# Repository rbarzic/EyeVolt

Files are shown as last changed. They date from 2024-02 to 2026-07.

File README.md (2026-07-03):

# Presentation

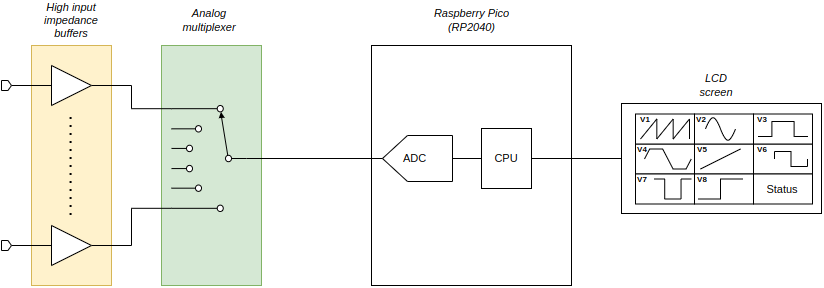
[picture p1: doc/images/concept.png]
General concept


EyeVolt 2.0 is a **12-channel DC voltage monitor** **and** an **8-channel
programmable DC voltage generator**, both built around a single Raspberry Pi
Pico (the RP2040 `U9`).

On the **monitor** side the Pico continuously samples up to twelve external
voltages and streams the raw ADC readings out over USB-serial, exactly like
v1.1. On the **generation** side the Pico produces eight independent 0 - 3.3 V
outputs by low-pass-filtering eight PWM channels and buffering them; a feedback
multiplexer lets the Pico read its own generated outputs back.

A Python **Terminal User Interface (TUI)** on the PC displays the live
monitored values, progress bars and sparkline trends. The PC software can
optionally expose the readings through an **MCP (Model Context Protocol)
server** so that AI assistants / automation can query the voltages
programmatically.

> **Software status (2.0):** the firmware and PC software currently committed
> in this repository are the **v1.1 code** — they implement the original
> voltage-monitoring protocol only and do **not** yet match the 2.0 hardware.
> See the [Software status](#software-status-20) section below for what works
> today and what is still to be done.

The board has two monitoring domains (unchanged ranges from v1.1):

| Group | Channels | Full-scale | Conditioning | Routed to |
|---|---|---|---|---|
| Low-voltage  | 0 - 7  (8 ch) | 0 - 3.3 V | unity-gain buffer only | MUX0 -> MUX1 (CH4) -> ADC0 (GP26) |
| High-voltage | 8 - 11 (4 ch) | 0 - 6.6 V | buffer + 2:1 resistive divider (÷2)  | MUX1 (CH0-CH3) -> ADC0 (GP26) |

Because the RP2040 ADC only accepts 0 - 3.3 V, the high-voltage channels are
divided by two on the board (so 6.6 V at the input => 3.3 V at the ADC); the PC
software then multiplies back by two to display the true input voltage.

---

# Hardware

## What changed from v1.1

The 2.0 board keeps the exact same 12-channel voltage-monitoring function and
ranges as v1.1, but the analog multiplexing hardware was reworked, and a full
voltage-generation stage was added:

| Area | v1.1 | v2.0 |
|---|---|---|
| Monitor MUX topology | two independent 74HCT4051, each feeding its own ADC pin (MUX0->GP26, MUX1->GP27) | the two 74HCT4051 are **cascaded** and only **one** ADC pin is used for monitoring (MUX0 -> MUX1 CH4 -> GP26) |
| Monitor select lines | MUX0: S0/S1/S2 = GP10/11/12, MUX1: S0/S1/S2 = GP21/20/19 | MUX0: S0/S1/S2 = **GP12/11/10**, MUX1: S0/S1/S2 = **GP19/20/21** (S0 and S2 swapped on both muxes; `~E` and S1 unchanged) |
| High-voltage input nets | `V55IN0..3` | `V50IN0..3` (same ÷2 divider, same 0 - 6.6 V range — name only) |
| Voltage generation | none | **8 PWM outputs (GP2-GP9)** -> 2nd-order RC low-pass filter -> unity-gain buffer -> J2 output header |
| Output readback | none | a 3rd 74HCT4051 (U12) multiplexes the 8 generated outputs back to **GP27 (ADC1)** |
| Front-panel headers | J2/J3 = TFT/touchscreen (unused) | J2 = **DAC output IDC 2x20** (8 analog outputs + 8 raw PWM taps + power); TFT headers removed |

The input connector **J1** (2x10 box header) is pin-compatible with v1.1.

## Architecture (block-level)

```
                                       Voltage MONITORING                                  Voltage GENERATION
 +-----------+   +-----------------------+                                                    +--------------------+
 |           |V33>+-->|U3/U8 buffer x8 |---VBUFF0..7--> |     | (CH0..7)       PWM GP2..GP9 -->| R(10k)-C(1uF)-R-C  |--> OPA316 buffer x8
 |  J1 input |    |   (0-3.3V domain)  |                 |     |                              |   2nd-order LPF    |     (U4-7,U13-16)
 | connector |    +-----------------------+               |     |                              +--------------------+          |
 | 2x10 box  |            |                              | U11 | (MUX0)                                              0R  | OUT_LINK
 | header    |V50>--+-->|U1 buffer x4|--+  +---+         | 8:1 | ----------+                                           |
 |           |    |   |(high-V in)  |  +->|/2 |->|U2|--> |     |           |   +--------------------+                     |
 |           |    |   +-------------+--+  +---+  (x4)    +-----+           |   | U12 74HCT4051      |                     |
 |           |    |        100k/100k divider               |CH4|----------->| DAC feedback mux   |<--- DAC_OUT0..7 <----+
 |           |    |                                         |     |           | (U12)              |
 +-----------+    |    +-->|U2 buffer x4|---VBUFF8..11--> | U10 | (MUX1)   +--------------------+
                  |    |   |(after div) |                  | 8:1 |                       | common
                  |    |   +------------+                  |     | (CH0..3=HV, CH4=MUX0, | -> GP27 / ADC1 (readback)
                  |    +----------------------------------->|     |  CH5..7=spare)
                                                       +----+-----+
                                                       | common -> GP26 / ADC0 (monitor)
                                                       +----------+
                                                           Raspberry Pi Pico (U9)
        USB-CDC serial  (9600 8N1)  ----> PC running eyevolt_mcp.py
```

In words (monitoring path):

1. The voltages to be measured arrive on connector **J1** (a 2x10 box header).
2. Every input is **buffered** by a rail-to-rail CMOS op-amp configured as a
   unity-gain voltage follower, giving the circuit a very high input impedance
   so it does not perturb the device under test.
   * Low-voltage inputs `V33IN0..3` -> `U3` (MCP6L04 quad); `V33IN4..7` -> `U8`
     (MCP6L04 quad).
   * High-voltage inputs `V50IN0..3` -> `U1` (MCP6L04 quad), then a **100 k /
     100 k divider** (÷2), then buffered again by `U2` (MCP6L04 quad) so the
     divider node is not loaded.
3. The 8 low-voltage buffered signals (`VBUFF0..7`) feed **MUX0** (`U11`, a
   74HCT4051 8:1 analog multiplexer).
4. The 4 high-voltage buffered signals (`VBUFF8..11`) feed channels CH0-CH3 of
   **MUX1** (`U10`, also a 74HCT4051). **MUX0's common output is routed into
   MUX1's CH4 input**, so MUX1 selects between the 4 HV channels and the whole
   MUX0 bank. CH5-CH7 of MUX1 are spare (currently unused).
5. **MUX1's common output goes to ADC0 (GP26)** — this is the only ADC pin used
   for monitoring. The Pico enables MUX1, selects CH4 to reach the MUX0 bank,
   then cycles MUX0 through its 8 channels; for HV channels it selects CH0-CH3
   directly.

Generation path:

1. The Pico generates eight independent PWM signals on **GP2..GP9**
   (`DAC_PWM0..7`).
2. Each PWM signal passes through a **2nd-order passive RC low-pass filter**
   (10 kΩ + 1 µF, then 10 kΩ + 1 µF; per-stage cutoff ≈ 16 Hz) which converts
   the duty cycle into a DC level (0 - 3.3 V proportional to duty cycle).
3. Each filtered DC level is buffered by a unity-gain **OPA316** rail-to-rail
   op-amp (`U4,U5,U6,U7,U13,U14,U15,U16`).
4. A 0 Ω **OUT_LINK** jumper (`R25-R28`, `R45-R48`) ties each buffer output to
   its `DAC_OUTn` net on connector **J2** (the link can be removed to isolate
   or re-route a channel).
5. A third 74HCT4051 (**`U12`**, the *DAC feedback mux*) multiplexes the 8
   `DAC_OUT` signals onto **ADC1 (GP27)** so the firmware can read back every
   generated voltage and verify / trim it.

## Bill of materials (main components)

| Ref | Part | Function |
|-----|---|---|
| U9 | Raspberry Pi Pico | MCU + dual ADC + USB-serial |
| U11 | 74HCT4051 | 8:1 analog multiplexer for the 3.3 V channels (**MUX0**) |
| U10 | 74HCT4051 | 8:1 analog multiplexer: HV channels CH0-3 + cascaded MUX0 on CH4 + spare CH5-7 (**MUX1**) |
| U12 | 74HCT4051 | 8:1 analog multiplexer for the 8 generated-output readback (**DAC feedback mux**) |
| U3, U8 | MCP6L04 (quad op-amp) | unity-gain buffers for the 8 low-voltage channels |
| U1 | MCP6L04 (quad op-amp) | input buffers for the 4 high-voltage channels |
| U2 | MCP6L04 (quad op-amp) | post-divider buffers for the 4 high-voltage channels |
| U4, U5, U6, U7, U13, U14, U15, U16 | OPA316 (single op-amp, SOT-23-5) | unity-gain buffers for the 8 generated outputs |
| R9-R12 | 100 kΩ | top leg of the 2:1 divider (one per HV channel) |
| R13-R16 | 100 kΩ | bottom leg of the divider to GND (one per HV channel) |
| R1-R8, R17-R24, R29-R44 | 10 kΩ | first and second series resistors of the 8 PWM low-pass filters |
| C3-C18, C27-C42 | 1 µF | filter capacitors of the 8 PWM low-pass filters (each with a DNP thru-hole alternate) |
| R25-R28, R45-R48 | 0 Ω (OUT_LINK) | jumpers linking each output buffer to its `DAC_OUT` net |
| C1-C2, C19-C26, C43-C47 | decoupling | local bypassing for the op-amps and the muxes |
| J1 | Conn_02x10 (2.54 mm box header) | voltage-monitor inputs + GND |
| J2 | IDC 2x20 (2.54 mm) | generation outputs: 8 analog `DAC_OUT`, 8 raw `DAC_PWM` taps, 5 V / 3.3 V / GND |
| H1-H4 | Mounting holes | mechanical |

The monitoring op-amps are Microchip **MCP6L04** (quad, 1 MHz, 85 µA,
rail-to-rail I/O) and the output buffers are TI **OPA316** (single, 2 MHz,
rail-to-rail I/O) — both low-cost, low-bias, supplied from the Pico's 3.3 V
rail. The pin-compatible MCP6024 and OPA4316 are kept as alternatives in
`doc/datasheets/opamp/`.

## Input connector J1 pinout (voltage monitor)

J1 is a 2x10 (2.54 mm) box header. The odd-numbered row carries the eight
low-voltage inputs (`V33IN0..7`); the even-numbered row carries the four
high-voltage inputs (`V50IN0..3`) plus ground. Pinout is compatible with v1.1.

> Pinout below is taken from the generated netlist (`hw/pcb/eyevolt.net`).
> Verify against the current schematic if in doubt.

| J1 pin | Signal | Range | EyeVolt channel |
|---|---|---|---|
| 1 | V33IN0 | 0 - 3.3 V  | ch 0  (MUX0 CH0) |
| 3 | V33IN1 | 0 - 3.3 V  | ch 1  (MUX0 CH1) |
| 5 | V33IN2 | 0 - 3.3 V  | ch 2  (MUX0 CH2) |
| 7 | V33IN3 | 0 - 3.3 V  | ch 3  (MUX0 CH3) |
| 9 | V33IN4 | 0 - 3.3 V  | ch 4  (MUX0 CH4) |
| 11 | V33IN5 | 0 - 3.3 V  | ch 5  (MUX0 CH5) |
| 13 | V33IN6 | 0 - 3.3 V  | ch 6  (MUX0 CH6) |
| 15 | V33IN7 | 0 - 3.3 V  | ch 7  (MUX0 CH7) |
| 2 | V50IN0 | 0 - 6.6 V  | ch 8  (MUX1 CH0) |
| 4 | V50IN1 | 0 - 6.6 V  | ch 9  (MUX1 CH1) |
| 6 | V50IN2 | 0 - 6.6 V  | ch 10 (MUX1 CH2) |
| 8 | V50IN3 | 0 - 6.6 V  | ch 11 (MUX1 CH3) |
| 10,12,14,16 | NC  | — | not connected |
| 17,18,19,20 | GND | — | signal / return ground |

## Output connector J2 pinout (voltage generation)

J2 is a 2x20 (2.54 mm) IDC header. Each signal is bussed across a pair of pins
(standard IDC ribbon style). It exposes the 8 **buffered analog outputs**
(`DAC_OUT0..7`), the 8 **raw PWM taps** (`DAC_PWM0..7`, also driven by the
Pico), and the 5 V / 3.3 V / GND power rails.

| J2 pins | Signal | Direction | Notes |
|---|---|---|---|
| 1, 2, 3, 4 | GND | — | signal / return ground |
| 5, 6 | VDD50 | power out | 5 V (VBUS) rail |
| 7, 8 | VDD33 | power out | 3.3 V rail |
| 9, 10 | DAC_OUT7 | analog out| buffered generated output 7 |
| 11, 12 | DAC_OUT6 | analog out| buffered generated output 6 |
| 13, 14 | DAC_OUT5 | analog out| buffered generated output 5 |
| 15, 16 | DAC_OUT4 | analog out| buffered generated output 4 |
| 17, 18 | DAC_OUT3 | analog out| buffered generated output 3 |
| 19, 20 | DAC_OUT2 | analog out| buffered generated output 2 |
| 21, 22 | DAC_OUT1 | analog out| buffered generated output 1 |
| 23, 24 | DAC_OUT0 | analog out| buffered generated output 0 |
| 25, 26 | DAC_PWM7 | digital | raw PWM tap 7 (driven by GP9) |
| 27, 28 | DAC_PWM6 | digital | raw PWM tap 6 (driven by GP8) |
| 29, 30 | DAC_PWM5 | digital | raw PWM tap 5 (driven by GP7) |
| 31, 32 | DAC_PWM4 | digital | raw PWM tap 4 (driven by GP6) |
| 33, 34 | DAC_PWM3 | digital | raw PWM tap 3 (driven by GP5) |
| 35, 36 | DAC_PWM2 | digital | raw PWM tap 2 (driven by GP4) |
| 37, 38 | DAC_PWM1 | digital | raw PWM tap 1 (driven by GP3) |
| 39, 40 | DAC_PWM0 | digital | raw PWM tap 0 (driven by GP2) |

## Analog conditioning detail

* **Low-voltage channels (0-7):** each input drives the `+` input of an op-amp
  voltage follower whose output is shorted to its `-` input. The output
  (`VBUFF0..7`) goes directly to one of MUX0's analog inputs. No scaling — the
  displayed voltage equals the measured voltage (up to the 3.3 V rail).

* **High-voltage channels (8-11):** each input is first buffered (U1, high
  impedance), then split by a 100 k / 100 k divider to GND, then buffered again
  (U2) before reaching MUX1. The two-stage buffering keeps the divider node
  high-impedance and accurate. The ADC therefore sees `Vin / 2`, and the PC
  software restores the real value by multiplying by 2 (`raw / 65536 * 6.6`).

## Multiplexing (74HCT4051)

Each 74HCT4051 selects one of 8 analog inputs onto a common pin `A` according to
the 3-bit address `S2 S1 S0`, while `~E` (active-low enable) gates the output.
When `~E = 1` the switch is high-impedance. The Pico drives these logic pins
directly. On the board, VEE is tied to GND (single-supply operation, 0 - VCC
analog range) and VCC is the 3.3 V rail.

**Monitor cascade:** in 2.0, MUX0's common is wired to **MUX1 channel 4**, so
the firmware must (a) enable MUX1 and address CH4 to "see through" to the
8 low-voltage channels, then (b) cycle MUX0; the high-voltage channels are read
by addressing MUX1 CH0-CH3 directly. All twelve channels exit on **GP26**.

**Feedback mux:** `U12` independently switches the 8 generated `DAC_OUT`
signals onto **GP27** so each output voltage can be measured back by the Pico.

## PWM generation chain

Each of the 8 output channels is identical:

```
GPn (PWM) -- R 10k -- (C 1uF to GND) -- R 10k -- (C 1uF to GND) -- OPA316 unity buffer -- 0R OUT_LINK -- DAC_OUTn -> J2
```

This is a 2nd-order passive RC low-pass filter (per-stage cutoff
`1/(2*pi*10k*1uF) ≈ 16 Hz`) followed by a rail-to-rail unity-gain buffer. The
steady-state output is `duty * 3.3 V` over the 0 - 3.3 V range. The filter
strongly attenuates the PWM carrier so the output is essentially DC; the buffer
provides a low-impedance output to the load via J2.

## Power

The board is powered by the Pico's USB connection. The 3.3 V rail (`VDD33`)
powers the op-amps and the multiplexers and serves as the ADC reference. A 5 V
rail (`VDD50` = VBUS) is also present and is exposed on the J2 output header.

---

# Firmware (Pico, MicroPython)

Location: `sw/pico/micropython/main.py`. It is plain MicroPython using the
`machine` module; `boot.py` is empty (USB-CDC is configured in the firmware
image, not at run time).

## Pico pin mapping (2.0 hardware)

| GPIO | Direction | Net (schematic) | Purpose |
|---|---|---|---|
| GP2  | out (PWM) | DAC_PWM0 | generation PWM, output 0 |
| GP3  | out (PWM) | DAC_PWM1 | generation PWM, output 1 |
| GP4  | out (PWM) | DAC_PWM2 | generation PWM, output 2 |
| GP5  | out (PWM) | DAC_PWM3 | generation PWM, output 3 |
| GP6  | out (PWM) | DAC_PWM4 | generation PWM, output 4 |
| GP7  | out (PWM) | DAC_PWM5 | generation PWM, output 5 |
| GP8  | out (PWM) | DAC_PWM6 | generation PWM, output 6 |
| GP9  | out (PWM) | DAC_PWM7 | generation PWM, output 7 |
| GP10 | out | MUX0_S2 | MUX0 address bit 2 |
| GP11 | out | MUX0_S1 | MUX0 address bit 1 |
| GP12 | out | MUX0_S0 | MUX0 address bit 0 |
| GP13 | out | MUX0_EB | MUX0 enable (`~E`, active low) |
| GP14 | out | DACMUX_S1 | DAC feedback mux address bit 1 |
| GP15 | out | DACMUX_S0 | DAC feedback mux address bit 0 |
| GP16 | out | DACMUX_S2 | DAC feedback mux address bit 2 |
| GP17 | out | DACMUX_EB | DAC feedback mux enable (`~E`, active low) |
| GP18 | out | MUX1_EB | MUX1 enable (`~E`, active low) |
| GP19 | out | MUX1_S0 | MUX1 address bit 0 |
| GP20 | out | MUX1_S1 | MUX1 address bit 1 |
| GP21 | out | MUX1_S2 | MUX1 address bit 2 |
| GP26 | in (ADC0) | MON_ADC_A | MUX1 common -> reads all 12 monitor channels (LV via cascade) |
| GP27 | in (ADC1) | DAC_FB_A | DAC feedback mux common -> reads back the 8 generated outputs |

## Principle of operation (v1.1-compatible monitoring)

> The firmware currently checked in (`main.py`) is the **v1.1** firmware: it
> drives MUX0 / MUX1 as two independent muxes and reads **two** ADC pins
> (GP26 + GP27). On the **2.0** hardware this is incorrect — MUX1's select
> lines are remapped and all 12 channels now arrive on **GP26 only** (GP27 is
> the DAC-feedback ADC). See [Software status](#software-status-20).

The intended v1.1-compatible scan (to be re-implemented for 2.0) repeatedly:

1. Selects **MUX1 CH4** (the cascade), then scans **MUX0** channels 0..7: for
   each channel it writes the 3-bit MUX0 address, asserts `~E`, waits for the
   switch and buffer to settle, then reads **ADC0 (GP26)**.
2. Scans **MUX1** channels 0..3 (the HV channels) directly, reading ADC0.
3. Prints two text lines (one per group) over USB-serial.

`read_u16()` returns a 16-bit value (0..65535) proportional to the voltage at
the ADC pin relative to the 3.3 V reference. The firmware sends the *raw* value
unchanged; all scaling is done on the PC side.

## Serial protocol

USB-CDC, **9600 baud, 8N1**, ASCII text. The Pico emits two lines per cycle:

```
1::VVVVV VVVVV VVVVV VVVVV VVVVV VVVVV VVVVV VVVVV
2::VVVVV VVVVV VVVVV VVVVV
```

* `1::` introduces the 8 low-voltage channels (0..7), space-separated,
  zero-padded to 5 digits.
* `2::` introduces the 4 high-voltage channels (8..11), space-separated.
* Values are raw 16-bit ADC codes (0..65535).

There is no request/response framing and no checksum: the device streams
continuously and the host synchronises on the `1::` / `2::` headers. The 2.0
firmware will keep this protocol so the PC software and the MCP tools remain
backward-compatible.

---

# PC software

The recommended version is `sw/pc/eyevolt_mcp.py` (a richer superset of the
older `sw/pc/eyevolt_pc.py`). It is a single-file Python application built with
**Textual** (TUI), **pyserial-asyncio** (serial), and an optional **MCP over
SSE** server (Starlette + Uvicorn).

## Serial acquisition & scaling

`SerialProtocol` buffers bytes until a newline, then `process_line()` decodes
each frame:

* `1::` frame -> 8 integers, converted with `raw / 65536 * 3.3`  (volts, 0-3.3 V)
* `2::` frame -> 4 integers, converted with `raw / 65536 * 6.6`  (volts, 0-6.6 V)

The resulting 12 float values are pushed into the 12 display widgets.

## Terminal User Interface (TUI)

`SerialTUI` lays out **12 `VoltageDisplay` widgets in a 3x4 grid**. Each widget
contains a label with the channel name and current value, a progress bar
showing the value as a percentage of the channel full-scale (3.3 V for
channels 0-7, 6.6 V for channels 8-11), and a sparkline of recent history
(rolling window, default 128 samples). A colour scheme highlights abnormal
rails:

| Voltage | Colour |
|---|---|
| < 0.5 V | white  |
| 0.5 - 0.8 V | yellow |
| 0.8 - 1.2 V | green  |
| >= 1.2 V | red |

## MCP server

When started with `--mcp`, an `EyeVoltMCPServer` runs an MCP server over
Server-Sent Events (SSE) on `127.0.0.1:8088` by default, in a background
thread. It exposes the live readings as tools that an MCP-compatible client
(e.g. an AI coding assistant) can call:

| Tool | Description |
|---|---|
| `get_voltages` | All enabled channels as `{name: voltage}` |
| `get_voltage` | One channel by name |
| `get_voltage_idx` | One channel by index (0-11) |
| `get_channel_info` | Full per-channel info (name, enabled, voltage, max) |
| `get_channel_history` | Sparkline history (percentages 0-100) for a named channel |

## Command-line usage

```
eyevolt_mcp.py [-h] [--text VAL=NAME,...] [--channel VAL=on|off,...]
               [--history N] [--mcp] [--mcp-host H] [--mcp-port P] [-v]
               PORT
```

* `PORT` — serial device, e.g. `/dev/ttyACM0` (Linux/macOS) or `COM3` (Windows).
* `--text` — rename channels, zero-based, e.g. `val0=VCORE,val1=VIO`.
* `--channel` — enable/disable channels, e.g. `val8=off,val9=off`. Channels not
  listed default to **on**; disabled channels show `----`.
* `--history` — sparkline length (default 128).
* `--mcp` — start the MCP/SSE server.
* `--mcp-host` / `--mcp-port` — MCP bind address (default `127.0.0.1:8088`).
* `-v` / `-vv` — info / debug logging.

Examples (see `sw/pc/readme.txt`):

```
./eyevolt_mcp.py --text val0=VCORE,val1=VIO /dev/ttyACM0

./eyevolt_mcp.py \
    --text val0=VCORE,val1=VMAX,val2=VMAIN,val3=VULP,val4=VPERIPH,\
val5=VCOREDIG,val6=VCORERAD,val7=VIO \
    --channel val8=off,val9=off,val10=off,val11=off \
    /dev/ttyACM0

./eyevolt_mcp.py --mcp /dev/ttyACM0        # also expose readings to MCP clients
```

---

# Software status (2.0)

The hardware described above is the **2.0** design, but the software in this
repository is still the **v1.1** implementation. Concretely:

| Feature | Status |
|---|---|
| 12-channel voltage monitoring (serial protocol `1::`/`2::`) | **Planned.** The protocol and PC side stay the same; only the Pico scan routine changes for the 2.0 MUX cascade / remapped select lines. The intent is for the device to expose the **same** v1.1 monitoring protocol by default. |
| Current `main.py` on 2.0 hardware | **Does not work as-is.** It uses two ADC pins and the v1.1 select-line mapping; on 2.0 all 12 channels arrive on GP26 and GP27 is the DAC-feedback ADC. |
| 8-channel voltage generation (PWM + filter + buffer) | **Not implemented.** Requires new firmware (PWM setup on GP2-GP9, duty-cycle commands) and PC/MCP tooling to set voltages. |
| Output readback via U12 / GP27 | **Not implemented.** Needs firmware + PC support to read and report generated voltages. |
| PC TUI / MCP server | **Working**, unchanged from v1.1 (monitoring only). |

### What the 2.0 firmware update needs (monitoring)

* Drive MUX0 select lines on the **new** GPIOs (S0=GP12, S1=GP11, S2=GP10).
* Drive MUX1 select lines on the **new** GPIOs (S0=GP19, S1=GP20, S2=GP21).
* To read the 8 low-voltage channels: enable MUX1, select **CH4** (cascade),
  then cycle MUX0 0..7 and read **ADC0 (GP26)**.
* To read the 4 high-voltage channels: select MUX1 **CH0..CH3** and read ADC0.
* Keep emitting the `1::` (8 values) / `2::` (4 values) lines so the PC
  software and MCP tools are unchanged.

### What the 2.0 generation feature needs

* PWM setup on GP2-GP9 with a carrier frequency well above the 16 Hz filter
  cutoff.
* A serial command set to set per-channel duty cycle (target voltage).
* Readback of the 8 `DAC_OUT` signals through U12 on **GP27 (ADC1)**.
* PC / MCP tooling to set and monitor the 8 generated voltages.

---

# Running the system end-to-end

1. **Flash the Pico** with a MicroPython image (USB-CDC enabled), then copy
   `sw/pico/micropython/main.py` onto it (the `sw/pico/micropython/Makefile`
   provides `make copy` via `rshell` and `make run` via `mpremote`). On power-up
   the Pico starts streaming `1::`/`2::` lines at 9600 baud.
2. **Set up the PC environment** (`requirements.txt`):
   `pip install -r requirements.txt` (textual, pyserial-asyncio, mcp, starlette,
   uvicorn, rich, ...).
3. **Run the TUI**, pointing it at the Pico's serial port and labelling the
   channels to match your DUT (example above).
4. **(Optional)** add `--mcp` and connect an MCP client to `http://127.0.0.1:8088/sse`.

> Note: step 1 assumes the firmware already matches the 2.0 monitoring routing.
> Until that update is done, the device will not produce correct readings on
> 2.0 hardware (see [Software status](#software-status-20)).

---

# End-to-end data path (summary)

```
MONITORING:
DUT rail -- J1 -- op-amp buffer (+÷2 divider on HV channels)
        -- 74HCT4051 MUX0 -> MUX1 CH4 / MUX1 CH0..3 (U11 -> U10, selected by GP10..13, GP19..21, GP18)
        -- Pico ADC0 (GP26)
        -- MicroPython reads raw 16-bit codes, prints "1::.." / "2::.."
        -- USB-CDC @9600 baud
        -- eyevolt_mcp.py (async serial reader)
        -- Textual TUI (value + bar + sparkline) and/or MCP/SSE server

GENERATION (not yet implemented):
PC target voltage -> serial command -> Pico sets PWM duty on GP2..GP9
        -> 2nd-order RC LPF (10k/1uF, ~16 Hz) -> OPA316 unity buffer
        -> 0R OUT_LINK -> DAC_OUT0..7 -> J2
        -> (readback) U12 74HCT4051 feedback mux -> Pico ADC1 (GP27)
```

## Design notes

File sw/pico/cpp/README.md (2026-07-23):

# EyeVolt 2.0 — C++ firmware (Pico / RP2040)

C++ reimplementation of the EyeVolt firmware for the **2.0 hardware**, built with
the [pico-sdk](https://github.com/raspberrypi/pico-sdk) via the
[pico-bootstrap](https://github.com/rbarzic/pico-bootstrap) submodule.

It replaces the v1.1 MicroPython code (`../micropython/main.py`) and adds the
two new v2.0 features: **8-channel voltage generation** (PWM + filter + buffer)
and **output readback**.

---

## What this firmware does

| Function | Detail |
|---|---|
| **12-channel monitoring** | Scans the cascaded MUX0 → MUX1 topology on **GP26/ADC0** (v2.0 routing). Emits the same `1::` / `2::` frames as v1.1 so the PC TUI/MCP software is unchanged. |
| **8-channel generation** | 8 PWM outputs on **GP2-GP9** → 2nd-order RC LPF → OPA316 buffer → J2. Set per-channel via serial commands. |
| **Output readback** | Feedback mux **U12** reads the 8 generated outputs back on **GP27/ADC1**; emitted as `3::` frames. |

---

## Build & flash

> The `pico-bootstrap` submodule is at `../imported/pico-bootstrap`. These
> targets reuse its downloaded SDK + tools (in `../imported/pico-bootstrap/deps`).

```bash
# One-time: download the SDK + build picotool/openocd (if not already done)
make download
make install

# Build the firmware
make build                       # → build/eyevolt.uf2 (and .elf/.hex/.bin)

# Flash over a Raspberry Pi Debug Probe
make identify-probe              # find the probe serial
make flash PROBE_SERIAL=<serial>
```

The Pico then enumerates as a USB-CDC serial port; the existing PC software
connects to it directly (`eyevolt_mcp.py /dev/ttyACM0`).

---

## Serial protocol

USB-CDC, ASCII text, line-based. The Pico streams continuously; the host
synchronises on the `N::` headers.

### Pico → host (data frames)

```
1::VVVVV VVVVV VVVVV VVVVV VVVVV VVVVV VVVVV VVVVV      ← 8 low-voltage  (0-3.3 V)
2::VVVVV VVVVV VVVVV VVVVV                              ← 4 high-voltage (0-6.6 V)
3::VVVVV VVVVV VVVVV VVVVV VVVVV VVVVV VVVVV VVVVV      ← 8 DAC readback (0-3.3 V)
```

Values are raw 16-bit ADC/PWM codes (0-65535). PC scaling:

* `1::` → `raw / 65536 * 3.3` V
* `2::` → `raw / 65536 * 6.6` V  (on-board ÷2 divider restored)
* `3::` → `raw / 65536 * 3.3` V

`1::` and `2::` are backward-compatible with v1.1. `3::` is new and ignored by
the current PC software.

### Host → Pico (commands, newline-terminated)

| Command | Effect | Reply |
|---|---|---|
| `SETDAC <ch> <raw>` | Set DAC channel `ch` (0-7) duty `raw` (0-65535) | `OK DAC<ch>=<raw>` |
| `SETMV <ch> <mv>` | Set DAC channel `ch` (0-7) to `mv` millivolts (0-3300) | `OK DAC<ch>=<mv>mV` |
| `OFF <ch>` | Set DAC channel `ch` (0-7) to 0 V | `OK DAC<ch>=0` |
| `OFFALL` | All DAC channels to 0 V | `OK all DAC=0` |
| `WFLOAD <nsteps> <mask_hex>` | Upload a binary waveform (see below) | `WFREADY <nbytes>` then `OK WFLOADED 0x<checksum>` |
| `WFPLAY [loop=0] [step_us=1000]` | Play the loaded waveform | `OK PLAYING nsteps=.. mask=.. loop=.. step_us=..` |
| `WFSTOP` | Stop playback (DACs hold last values) | `OK STOPPED step=<n>` |
| `WFSTATUS` | Query playback state | `WFSTAT <state> <step> <nsteps> <mask>` |
| `VERSION` | Print firmware version | `VERSION <ver>` |
| `HELP` | List commands | (help text) |

Errors reply `ERROR ...`. Commands are uppercase.

---

## Waveform playback

Upload a pre-computed waveform (8 channels × up to 2048 steps × 16-bit) into
Pico SRAM and play it back at a fixed step rate (default 1 ms/step → 2.048 s for
a full 2048-step run). A hardware repeating timer writes each step's active
channels to the PWM registers in IRQ context, so monitoring (`1::`/`2::`) keeps
running during playback. The `3::` readback frame is suppressed while playing.

Channels are marked **active** or **inactive** via the mask. Inactive channels
are never touched by playback — they hold whatever manual (`SETMV`/`SETDAC`)
value they had, so you can mix a driven waveform with static offsets.

### `WFLOAD` upload sequence

```
host → pico : WFLOAD 2048 0xFF\n
pico → host : WFREADY 32768\n              (nsteps × 8 × 2 bytes expected)
host → pico : <32768 raw bytes>            uint16 little-endian, step-major
pico → host : OK WFLOADED 0x0BFF7801\n      (32-bit additive checksum)
```

Binary layout: `byte_offset = (step × 8 + channel) × 2`, value
`round(mv / 3300 × 65535)` as little-endian `uint16`. Upload aborts with
`ERROR timeout (n/N bytes)` after 5 s.

### Host tools (`../tools/`)

```bash
# 1. Convert a PWL text description to a .bin (+ .meta sidecar with the mask)
python3 ../tools/pwl_to_waveform.py ../tools/examples/demo.pwl -o demo.bin

# 2. Upload and play (mask read from demo.meta automatically)
python3 ../tools/wf_upload.py /dev/ttyACM0 demo.bin --play
python3 ../tools/wf_upload.py /dev/ttyACM0 demo.bin --loop --step-us 500
```

See `../tools/` for the PWL format and example waveforms under
`../tools/examples/`.

---

## v2.0 hardware pin map

| GPIO | Direction | Net | Purpose |
|---|---|-----|---|
| GP2-GP9 | out (PWM) | DAC_PWM0..7 | 8 generation outputs |
| GP10 | out | MUX0_S2 | MUX0 address bit 2 |
| GP11 | out | MUX0_S1 | MUX0 address bit 1 |
| GP12 | out | MUX0_S0 | MUX0 address bit 0 |
| GP13 | out | MUX0_EB | MUX0 enable (~E) |
| GP14 | out | DACMUX_S1 | DAC feedback mux bit 1 |
| GP15 | out | DACMUX_S0 | DAC feedback mux bit 0 |
| GP16 | out | DACMUX_S2 | DAC feedback mux bit 2 |
| GP17 | out | DACMUX_EB | DAC feedback mux enable (~E) |
| GP18 | out | MUX1_EB | MUX1 enable (~E) |
| GP19 | out | MUX1_S0 | MUX1 address bit 0 |
| GP20 | out | MUX1_S1 | MUX1 address bit 1 |
| GP21 | out | MUX1_S2 | MUX1 address bit 2 |
| GP26 | in (ADC0) | MON_ADC | all 12 monitor channels (via cascaded MUX1) |
| GP27 | in (ADC1) | DAC_FB | 8 generated-output readback (via U12) |

### Monitoring cascade (v2.0 vs v1.1)

In v1.1 the two muxes were independent, each feeding its own ADC pin. In v2.0:

1. **MUX0's common** is wired to **MUX1 channel 4** (cascade).
2. To read the 8 LV channels: hold MUX1 on CH4, cycle MUX0 0..7, read GP26.
3. To read the 4 HV channels: select MUX1 CH0..3 directly, read GP26.
4. S0 and S2 are swapped on both muxes vs v1.1.

### Generation chain

```
GPn (PWM, ~1.9 kHz) → R 10k → C 1µF → R 10k → C 1µF → OPA316 buffer → 0R → DAC_OUTn → J2
                       (2nd-order RC LPF, ~16 Hz cutoff)                              ↑ readback via U12 → GP27
```

---

## Source layout

```
src/
├── main.cpp        main loop: scan → emit 1::/2::/3:: → poll commands
├── pins.h          v2.0 hardware pin map & timing constants
├── mux.h           generic 74HCT4051 driver (header-only)
├── monitor.{h,cpp} 12-channel cascade scan on GP26
└── generator.{h,cpp} 8-channel PWM generation + U12 readback on GP27
```

---

## Notes

* ADC readings are 4× oversampled (vs single sample in MicroPython) to reduce the
  RP2040 ADC noise. The 16-bit output format is unchanged.
* The mux settle time is 1 ms (vs 10 ms in MicroPython); the buffers and switches
  settle in well under 1 µs, so this only raises the refresh rate (~50 Hz). Adjust
  `MUX_SETTLE_US` in `pins.h` if needed.
* USB CDC is used for stdio (`printf`/`getchar`), matching the MicroPython version.
  The "9600 baud" requested by the PC is irrelevant for USB CDC.

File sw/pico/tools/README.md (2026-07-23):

# EyeVolt waveform host tools

Host-side tools to build and upload pre-computed waveforms for the EyeVolt 2.0
firmware (`../cpp`). A waveform is 8 channels × up to 2048 steps × 16-bit,
played back on the Pico at a fixed step rate (default 1 ms/step).

| Tool | Purpose |
|---|---|
| `pwl_to_waveform.py` | Convert a PWL text description → `.bin` (+ `.meta` sidecar) |
| `wf_upload.py` | Upload a `.bin` to the Pico over USB serial and optionally play it |

Requires Python 3 and, for uploading, `pyserial` (`pip install pyserial`).

---

## PWL format

A PWL file lists the channels you want to drive. Each channel is defined by a
set of piecewise-linear points; the converter linearly interpolates between them
to fill every step. Channels **not** listed are inactive: their mask bit is 0
and the firmware never drives them during playback (they hold their manual
`SETMV`/`SETDAC` value).

```text
# Comments start with '#'. Blank lines are ignored.

STEPS 2048              # required, 1..2048

# CH<n>  <mv>@<step>  <mv>@<step>  ...   (n = 0..7, at least 2 points)
# millivolts 0..3300, steps ascending, 0..STEPS-1.

CH0  0@0  3300@1024  0@2047     # triangle 0 -> 3.3 V -> 0
CH3  1650@0  1650@2047          # constant 1.65 V
```

### Rules

| Rule | Detail |
|---|---|
| `STEPS <n>` | Required. `1 ≤ n ≤ 2048`. |
| `CH<n> <mv>@<step> ...` | ≥ 2 points, steps ascending, `0 ≤ step < STEPS`. |
| Duplicate `CHn` | Error. |
| `mv` outside `0..3300` | Error. |
| Channel not listed | Inactive (mask bit 0, data zeroed). |

### Interpolation

For points `(t0,v0), (t1,v1), ...`:

- `step ≤ t0` → `v0` (hold first)
- `ti ≤ step ≤ ti+1` → linear between the two points
- `step ≥ t_last` → `v_last` (hold last)

Raw code: `raw = round(mv / 3300 × 65535)`, clamped to `0..65535`.

---

## Usage

```bash
# Preview a per-channel summary (no files written)
python3 pwl_to_waveform.py examples/demo.pwl --preview

# Convert → demo.bin + demo.meta
python3 pwl_to_waveform.py examples/demo.pwl -o demo.bin

# Upload and play once
python3 wf_upload.py /dev/ttyACM0 demo.bin --play

# Upload, loop at 500 µs/step, stop after 5 s
python3 wf_upload.py /dev/ttyACM0 demo.bin --loop --step-us 500 --stop-after 5
```

`pwl_to_waveform.py` writes a `.meta` sidecar (`{"mask", "nsteps", "checksum"}`)
next to the `.bin`. `wf_upload.py` reads it automatically to pick the active
mask; override with `--mask 0x09` or it defaults to `0xFF`.

`wf_upload.py` computes the same 32-bit additive checksum the firmware reports
and aborts on mismatch.

---

## Examples

| File | Shape |
|---|---|
| `examples/triangle.pwl` | CH0 triangle 0 → 3.3 V → 0 over 2048 steps |
| `examples/demo.pwl` | CH0 triangle, CH1 square wave, CH3 constant 1.65 V |

### Polaris

```bash
make play
make off
```

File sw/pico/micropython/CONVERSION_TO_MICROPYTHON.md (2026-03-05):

# CircuitPython to MicroPython Conversion Notes

This document summarizes the changes made when converting from CircuitPython to MicroPython for the Raspberry Pi Pico.

## File Structure Changes

- **CircuitPython**: Main code file is `code.py`
- **MicroPython**: Main code file is `main.py`
- **boot.py**: Both versions use this file, but CircuitPython uses it for USB CDC configuration while MicroPython typically doesn't need it

## Import Changes

| CircuitPython | MicroPython |
|---|---|
| `import board` | Not needed - use pin numbers directly |
| `import digitalio` | `import machine` |
| `import analogio` | `import machine` |
| `import usb_cdc` | Not needed - standard `print()` uses USB serial |
| `import keypad` | `import machine` (if needed) |

## Pin Configuration

### Digital I/O

**CircuitPython:**
```python
import board
import digitalio

pin = digitalio.DigitalInOut(board.GP13)
pin.direction = digitalio.Direction.OUTPUT
pin.value = True
```

**MicroPython:**
```python
import machine

pin = machine.Pin(13, machine.Pin.OUT)
pin.value(1)
```

### ADC (Analog Input)

**CircuitPython:**
```python
import board
import analogio

adc = analogio.AnalogIn(board.GP26)
raw_value = adc.value
voltage = (raw_value / 65535) * adc.reference_voltage
```

**MicroPython:**
```python
import machine

adc = machine.ADC(26)  # Use pin number directly
raw_value = adc.read_u16()
# Note: reference_voltage not directly available in MicroPython
```

## Key Differences

### 1. Pin Numbering
- **CircuitPython**: Uses `board.GPxx` objects
- **MicroPython**: Uses integer pin numbers directly (e.g., `13` for GP13)

### 2. Setting Pin Values
- **CircuitPython**: `pin.value = True/False`
- **MicroPython**: `pin.value(1/0)` or `pin.value(True/False)`

### 3. ADC Values
- **CircuitPython**: `adc.value` returns 16-bit value (0-65535)
- **MicroPython**: `adc.read_u16()` returns 16-bit value (0-65535)

### 4. Reference Voltage
- **CircuitPython**: `adc.reference_voltage` provides the ADC reference voltage
- **MicroPython**: No built-in property - typically 3.3V on Pico, calculate manually if needed

### 5. USB CDC (Serial Communication)
- **CircuitPython**: Requires `usb_cdc` module and configuration in `boot.py`
- **MicroPython**: Standard `print()` outputs to USB serial automatically

## Mux Control Functions

The multiplexer control logic remains the same, only the pin access syntax changed:

```python
# Setting select lines - same logic, different syntax
mux0_S0.value(b0)  # MicroPython
# vs
mux0_S0.value = b0  # CircuitPython
```

## Timing

Both use the same `time` module:
```python
import time
time.sleep(0.01)  # Works in both
```

## Notes

- MicroPython's `machine` module is more low-level and closer to hardware
- Pin numbers in MicroPython refer to GPIO numbers (GPxx → xx)
- The LSP errors you see when editing MicroPython code are normal - the `machine` module only exists on the device, not on your development machine

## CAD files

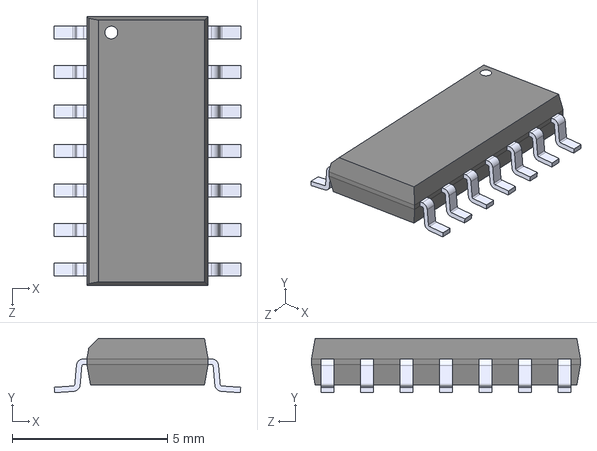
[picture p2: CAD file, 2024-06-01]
hw/pcb/parts/MCP6024-I_SL/MCP6024-I_SL.step
6.00 x 1.75 x 8.65 mm

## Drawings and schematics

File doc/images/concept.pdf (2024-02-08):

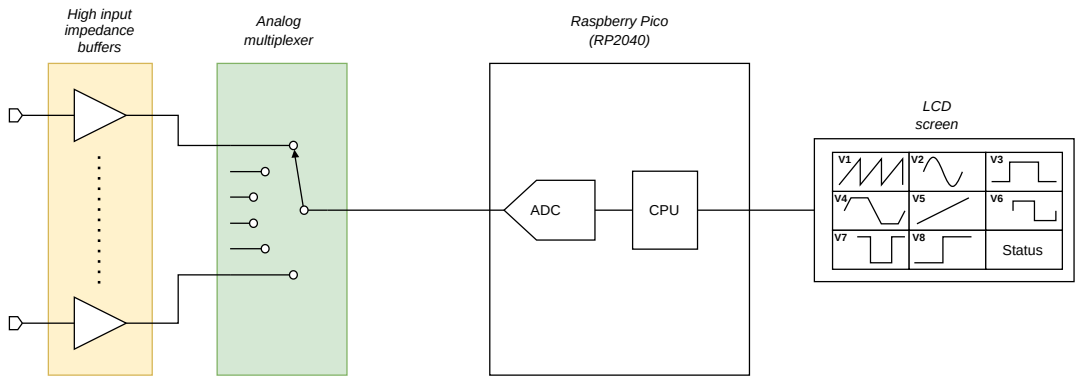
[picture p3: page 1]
High input impedance buffers; Analog multiplexer; ADC; CPU; Raspberry Pico (RP2040); LCD screen; Status

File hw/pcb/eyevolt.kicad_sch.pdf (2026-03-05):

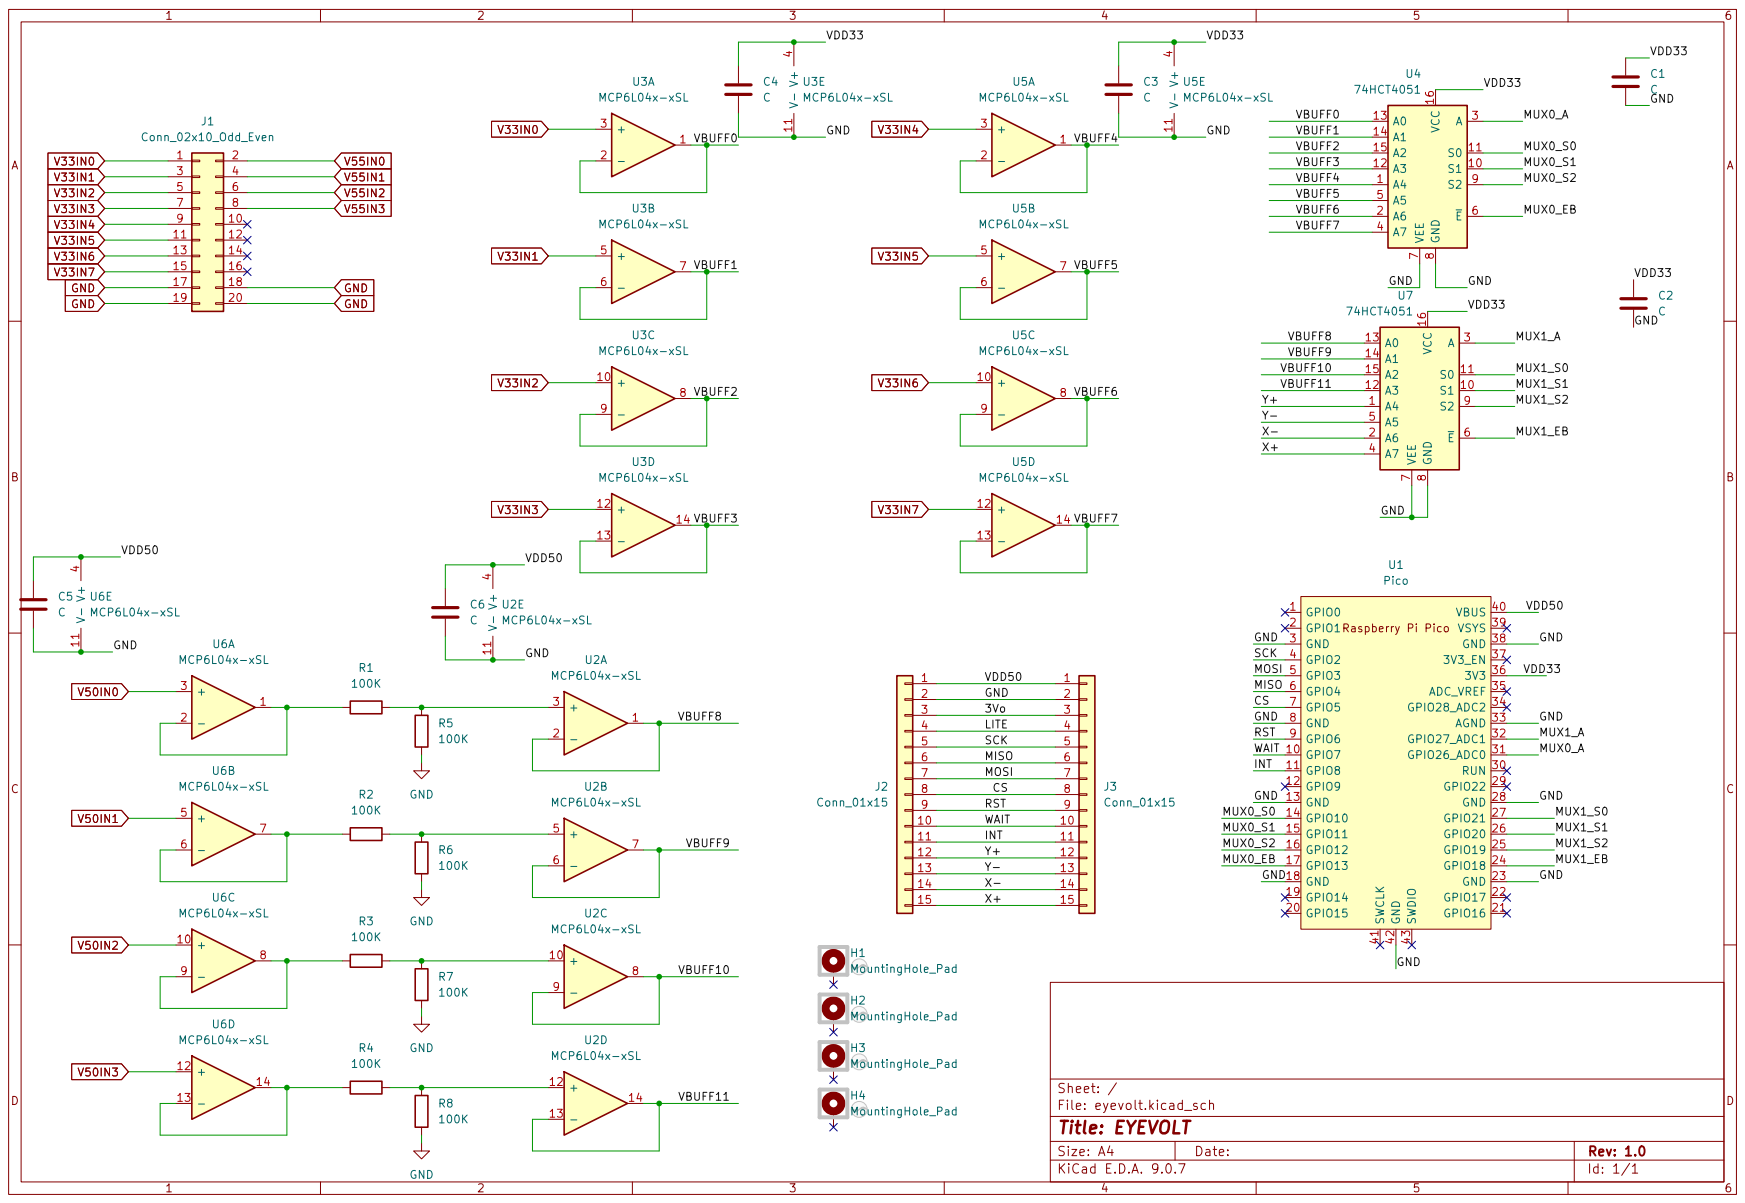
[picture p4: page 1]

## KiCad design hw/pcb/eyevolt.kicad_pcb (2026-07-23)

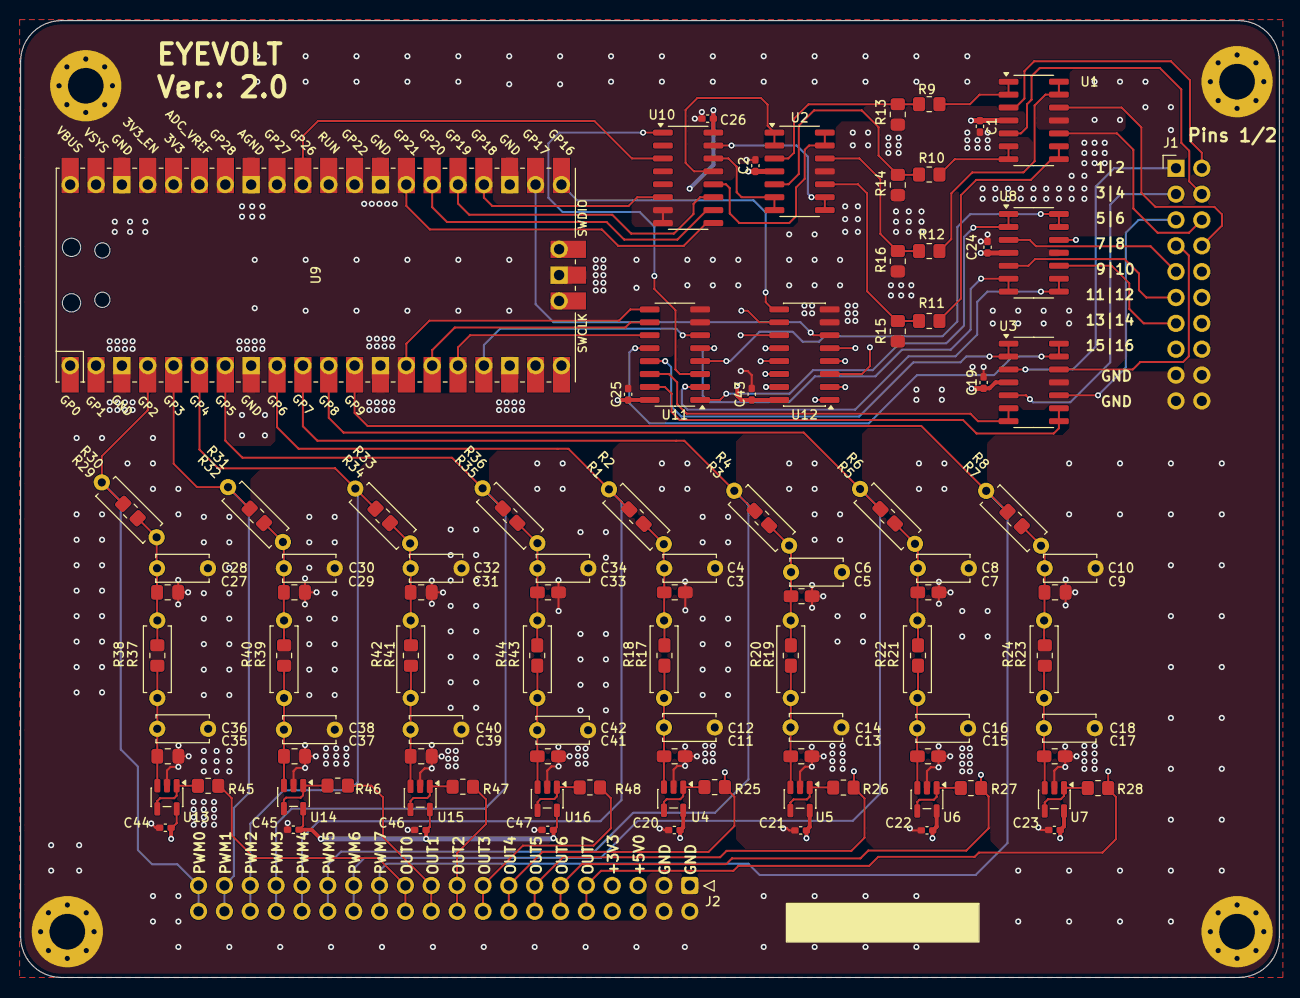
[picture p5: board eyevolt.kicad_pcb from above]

Board: 4 copper layers, 123.7 x 94.0 mm, 117 parts (0 on the bottom side), 90 nets.

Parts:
C1, C2, C19, C24, C25, C26: C; C_0402_1005Metric_Pad0.74x0.62mm_HandSolder
C3, C5, C7, C9, C11, C13, C15, C17, C27, C29, C31, C33, C35, C37, C39, C41: 1uF; C_0805_2012Metric_Pad1.18x1.45mm_HandSolder
C4, C6, C8, C10, C12, C14, C16, C18, C28, C30, C32, C34, C36, C38, C40, C42: DNP 1uF TH ALT; C_Disc_D5.0mm_W2.5mm_P5.00mm
C20, C21, C22, C23, C43, C44, C45, C46, C47: 100nF; C_0402_1005Metric_Pad0.74x0.62mm_HandSolder
H1, H2, H3, H4: MountingHole_Pad; MountingHole_3.5mm_Pad_Via
J1: Conn_02x10_Odd_Even; PinHeader_2x10_P2.54mm_Horizontal
J2: DAC_PWM_DAC_OUT_2x20; IDC-Header_2x20_P2.54mm_Horizontal
R1, R3, R5, R7, R17, R19, R21, R23, R29, R31, R33, R35, R37, R39, R41, R43: 10k; R_0805_2012Metric_Pad1.20x1.40mm_HandSolder
R2, R4, R6, R8, R18, R20, R22, R24, R30, R32, R34, R36, R38, R40, R42, R44: DNP 10k TH ALT; R_Axial_DIN0207_L6.3mm_D2.5mm_P7.62mm_Horizontal
R9, R10, R11, R12, R13, R14, R15, R16: 100K; R_0805_2012Metric_Pad1.20x1.40mm_HandSolder
R25, R26, R27, R28, R45, R46, R47, R48: 0R OUT_LINK; R_0805_2012Metric_Pad1.20x1.40mm_HandSolder
U1, U2, U3, U8: MCP6L04x-xSL; SOIC-14_3.9x8.7mm_P1.27mm
U4, U5, U6, U7, U13, U14, U15, U16: OPA316QDBVTQ1; SOT-23-5
U9: Pico; RPi_Pico_SMD_TH
U10, U11: 74HCT4051; SOIC-16_3.9x9.9mm_P1.27mm
U12: 74HCT4051 DAC_FB_MUX; SOIC-16_3.9x9.9mm_P1.27mm

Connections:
/DAC0_BUF: R45.1, U13.1, U13.4 (-)
/DAC0_FILT: C35.1, C36.1, R37.2, R38.2, U13.3 (+)
/DAC0_RC1: C27.1, C28.1, R29.2, R30.2, R37.1, R38.1
/DAC1_BUF: R46.1, U14.1, U14.4 (-)
/DAC1_FILT: C37.1, C38.1, R39.2, R40.2, U14.3 (+)
/DAC1_RC1: C29.1, C30.1, R31.2, R32.2, R39.1, R40.1
/DAC2_BUF: R47.1, U15.1, U15.4 (-)
/DAC2_FILT: C39.1, C40.1, R41.2, R42.2, U15.3 (+)
/DAC2_RC1: C31.1, C32.1, R33.2, R34.2, R41.1, R42.1
/DAC3_BUF: R48.1, U16.1, U16.4 (-)
/DAC3_FILT: C41.1, C42.1, R43.2, R44.2, U16.3 (+)
/DAC3_RC1: C33.1, C34.1, R35.2, R36.2, R43.1, R44.1
/DAC4_BUF: R25.1, U4.1, U4.4 (-)
/DAC4_FILT: C11.1, C12.1, R17.2, R18.2, U4.3 (+)
/DAC4_RC1: C3.1, C4.1, R1.2, R2.2, R17.1, R18.1
/DAC5_BUF: R26.1, U5.1, U5.4 (-)
/DAC5_FILT: C13.1, C14.1, R19.2, R20.2, U5.3 (+)
/DAC5_RC1: C5.1, C6.1, R3.2, R4.2, R19.1, R20.1
/DAC6_BUF: R27.1, U6.1, U6.4 (-)
/DAC6_FILT: C15.1, C16.1, R21.2, R22.2, U6.3 (+)
/DAC6_RC1: C7.1, C8.1, R5.2, R6.2, R21.1, R22.1
/DAC7_BUF: R28.1, U7.1, U7.4 (-)
/DAC7_FILT: C17.1, C18.1, R23.2, R24.2, U7.3 (+)
/DAC7_RC1: C9.1, C10.1, R7.2, R8.2, R23.1, R24.1
/DACMUX_EB: U9.22 (GPIO17), U12.6 (~E)
/DACMUX_S0: U9.20 (GPIO15), U12.11 (S0)
/DACMUX_S1: U9.19 (GPIO14), U12.10 (S1)
/DACMUX_S2: U9.21 (GPIO16), U12.9 (S2)
/DAC_FB_A: U9.32 (GPIO27_ADC1), U12.3 (A)
/DAC_OUT0: J2.23, J2.24, R45.2, U12.13 (A0)
/DAC_OUT1: J2.21, J2.22, R46.2, U12.14 (A1)
/DAC_OUT2: J2.19, J2.20, R47.2, U12.15 (A2)
/DAC_OUT3: J2.17, J2.18, R48.2, U12.12 (A3)
/DAC_OUT4: J2.15, J2.16, R25.2, U12.1 (A4)
/DAC_OUT5: J2.13, J2.14, R26.2, U12.5 (A5)
/DAC_OUT6: J2.11, J2.12, R27.2, U12.2 (A6)
/DAC_OUT7: J2.9, J2.10, R28.2, U12.4 (A7)
/DAC_PWM0: J2.39, J2.40, R29.1, R30.1, U9.4 (GPIO2)
/DAC_PWM1: J2.37, J2.38, R31.1, R32.1, U9.5 (GPIO3)
/DAC_PWM2: J2.35, J2.36, R33.1, R34.1, U9.6 (GPIO4)
/DAC_PWM3: J2.33, J2.34, R35.1, R36.1, U9.7 (GPIO5)
/DAC_PWM4: J2.31, J2.32, R1.1, R2.1, U9.9 (GPIO6)
/DAC_PWM5: J2.29, J2.30, R3.1, R4.1, U9.10 (GPIO7)
/DAC_PWM6: J2.27, J2.28, R5.1, R6.1, U9.11 (GPIO8)
/DAC_PWM7: J2.25, J2.26, R7.1, R8.1, U9.12 (GPIO9)
/MON_ADC_A: U9.31 (GPIO26_ADC0), U10.3 (A)
/MUX0_A_TO_MUX1: U10.1 (A4), U11.3 (A)
/MUX0_EB: U9.17 (GPIO13), U11.6 (~E)
/MUX0_S0: U9.16 (GPIO12), U11.11 (S0)
/MUX0_S1: U9.15 (GPIO11), U11.10 (S1)
/MUX0_S2: U9.14 (GPIO10), U11.9 (S2)
/MUX1_EB: U9.24 (GPIO18), U10.6 (~E)
/MUX1_S0: U9.25 (GPIO19), U10.11 (S0)
/MUX1_S1: U9.26 (GPIO20), U10.10 (S1)
/MUX1_S2: U9.27 (GPIO21), U10.9 (S2)
/VBUFF0: U3.1, U3.2 (-), U11.13 (A0)
/VBUFF1: U3.6 (-), U3.7, U11.14 (A1)
/VBUFF2: U3.8, U3.9 (-), U11.15 (A2)
/VBUFF3: U3.13 (-), U3.14, U11.12 (A3)
/VBUFF4: U8.1, U8.2 (-), U11.1 (A4)
/VBUFF5: U8.6 (-), U8.7, U11.5 (A5)
/VBUFF6: U8.8, U8.9 (-), U11.2 (A6)
/VBUFF7: U8.13 (-), U8.14, U11.4 (A7)
/VBUFF8: U2.1, U2.2 (-), U10.13 (A0)
/VBUFF9: U2.6 (-), U2.7, U10.14 (A1)
/VBUFF10: U2.8, U2.9 (-), U10.15 (A2)
/VBUFF11: U2.13 (-), U2.14, U10.12 (A3)
/VDD33: C19.1, C20.1, C21.1, C22.1, C23.1, C24.1, C25.1, C26.1, C43.1, C44.1, C45.1, C46.1, C47.1, J2.7, J2.8, U3.4 (V+), U4.5 (V+), U5.5 (V+), U6.5 (V+), U7.5 (V+), U8.4 (V+), U9.36 (3V3), U10.16 (VCC), U11.16 (VCC), U12.16 (VCC), U13.5 (V+), U14.5 (V+), U15.5 (V+), U16.5 (V+)
/VDD50: C1.1, C2.1, J2.5, J2.6, U1.4 (V+), U2.4 (V+), U9.40 (VBUS)
GND: C1.2, C2.2, C3.2, C4.2, C5.2, C6.2, C7.2, C8.2, C9.2, C10.2, C11.2, C12.2, C13.2, C14.2, C15.2, C16.2, C17.2, C18.2, C19.2, C20.2, C21.2, C22.2, C23.2, C24.2, C25.2, C26.2, C27.2, C28.2, C29.2, C30.2, C31.2, C32.2, C33.2, C34.2, C35.2, C36.2, C37.2, C38.2, C39.2, C40.2, C41.2, C42.2, C43.2, C44.2, C45.2, C46.2, C47.2, H1.1 (1_1), H2.1 (1_1), H3.1 (1_1), H4.1 (1_1), J1.17, J1.18, J1.19, J1.20, J2.1, J2.2, J2.3, J2.4, R13.1, R14.1, R15.1, R16.1, U1.11 (V-), U2.11 (V-), U3.11 (V-), U4.2 (V-), U5.2 (V-), U6.2 (V-), U7.2 (V-), U8.11 (V-), U9.3 (GND), U9.8 (GND), U9.13 (GND), U9.18 (GND), U9.23 (GND), U9.28 (GND), U9.33 (AGND), U9.38 (GND), U9.42 (GND), U10.7 (VEE), U10.8 (GND), U11.7 (VEE), U11.8 (GND), U12.7 (VEE), U12.8 (GND), U13.2 (V-), U14.2 (V-), U15.2 (V-), U16.2 (V-)
unnamed: R9.1, U1.1, U1.2 (-)
unnamed: R10.1, U1.6 (-), U1.7
unnamed: R11.1, U1.8, U1.9 (-)
unnamed: R12.1, U1.13 (-), U1.14
unnamed: R9.2, R13.2, U2.3 (+)
unnamed: R10.2, R14.2, U2.5 (+)
unnamed: R11.2, R15.2, U2.10 (+)
unnamed: R12.2, R16.2, U2.12 (+)
V33IN0: J1.1, U3.3 (+)
V33IN1: J1.3, U3.5 (+)
V33IN2: J1.5, U3.10 (+)
V33IN3: J1.7, U3.12 (+)
V33IN4: J1.9, U8.3 (+)
V33IN5: J1.11, U8.5 (+)
V33IN6: J1.13, U8.10 (+)
V33IN7: J1.15, U8.12 (+)
V50IN0: J1.2, U1.3 (+)
V50IN1: J1.4, U1.5 (+)
V50IN2: J1.6, U1.10 (+)
V50IN3: J1.8, U1.12 (+)

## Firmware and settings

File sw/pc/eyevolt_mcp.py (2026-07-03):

#!/usr/bin/env python3
import argparse
import asyncio
import json
import logging
import queue
import threading
from statistics import mean

import serial_asyncio
import uvicorn
from mcp.server import Server
from mcp.server.sse import SseServerTransport
from mcp.types import Tool, TextContent
from rich.logging import RichHandler
from starlette.applications import Starlette
from starlette.routing import Route
from textual.app import App, ComposeResult
from textual.containers import Vertical
from textual.widget import Widget
from textual.widgets import Label, ProgressBar, Sparkline


def get_color(value: float) -> str:
    if value < 0.5:
        return "white"
    elif value < 0.8:
        return "yellow"
    elif value < 1.2:
        return "#66FF66"
    else:
        return "#FF6666"


class VoltageDisplay(Widget):
    def __init__(self, static_text: str, index: int, enabled: bool = True, history_limit: int = 128, **kwargs) -> None:
        super().__init__(**kwargs)
        self.static_text = static_text
        self.index = index
        self.enabled = enabled
        self.history: list[int] = []
        self.history_limit = history_limit

    def compose(self) -> ComposeResult:
        yield Vertical(
            Label(f"{self.static_text}: 0.00", id=f"label_{self.index}"),
            ProgressBar(total=100, id=f"progress_{self.index}"),
            Sparkline(data=self.history, summary_function=mean, id=f"spark_{self.index}")
        )

    def update_value(self, new_value: float):
        label = self.query_one(f"#label_{self.index}", Label)
        progress_bar = self.query_one(f"#progress_{self.index}", ProgressBar)
        sparkline = self.query_one(f"#spark_{self.index}", Sparkline)

        if not self.enabled:
            label.update(f"{self.static_text}: ----")
            progress_bar.progress = 0
            progress_bar.styles.bar_color = "grey"
            sparkline.data = []
            sparkline.refresh()
            return

        max_val = 3.3 if self.index < 8 else 6.6
        pct = int(new_value / max_val * 100)
        color = get_color(new_value)

        label.update(f"{self.static_text}: " + f"[bold][{color}]{new_value:.2f}[/{color}][/bold]")
        progress_bar.progress = pct
        progress_bar.styles.bar_color = color

        self.history.append(pct)
        if len(self.history) > self.history_limit:
            self.history.pop(0)
        sparkline.data = [0, 100] + self.history
        sparkline.refresh()


class DacDisplay(Widget):
    """Compact DAC readback: a single live label (no graph / progress bar)."""

    DEFAULT_CSS = """
    DacDisplay {
        height: 1;
        padding: 0 1;
        content-align: center middle;
    }
    """

    def __init__(self, label_text: str, index: int, **kwargs) -> None:
        super().__init__(**kwargs)
        self.label_text = label_text
        self.index = index

    def compose(self) -> ComposeResult:
        yield Label(f"{self.label_text}: 0.00", id=f"dac_label_{self.index}")

    def update_value(self, voltage: float) -> None:
        color = get_color(voltage)
        self.query_one(f"#dac_label_{self.index}", Label).update(
            f"{self.label_text}: [bold][{color}]{voltage:.2f}[/{color}][/bold]"
        )


class SerialProtocol(asyncio.Protocol):
    def __init__(self, tui_app: "SerialTUI"):
        self.app = tui_app
        self.buffer = bytearray()

    def connection_made(self, transport):
        self.transport = transport
        self.app.log("Serial connection established.")

    def data_received(self, data: bytes):
        self.buffer.extend(data)
        while b"\n" in self.buffer:
            line, sep, self.buffer = self.buffer.partition(b"\n")
            try:
                line = line.decode("ascii").strip()
            except UnicodeDecodeError:
                self.app.log("Error decoding line from serial port.")
                continue
            self.process_line(line)

    def process_line(self, line: str):
        if line.startswith("1::"):
            parts = line[3:].strip().split()
            if len(parts) != 8:
                self.app.log(f"Unexpected number of values in header 1: {parts}")
                return
            try:
                raw_values = [int(part) for part in parts]
            except ValueError:
                self.app.log("Header 1: one of the values is not an integer.")
                return
            conv_values = [raw / 65536.0 * 3.3 for raw in raw_values]
            self.app.update_values(list(range(0, 8)), conv_values)
        elif line.startswith("2::"):
            parts = line[3:].strip().split()
            if len(parts) != 4:
                self.app.log(f"Unexpected number of values in header 2: {parts}")
                return
            try:
                raw_values = [int(part) for part in parts]
            except ValueError:
                self.app.log("Header 2: one of the values is not an integer.")
                return
            conv_values = [raw / 65536.0 * 6.6 for raw in raw_values]
            self.app.update_values(list(range(8, 12)), conv_values)
        elif line.startswith("3::"):
            parts = line[3:].strip().split()
            if len(parts) != 8:
                self.app.log(f"Unexpected number of values in header 3: {parts}")
                return
            try:
                raw_values = [int(part) for part in parts]
            except ValueError:
                self.app.log("Header 3: one of the values is not an integer.")
                return
            conv_values = [raw / 65536.0 * 3.3 for raw in raw_values]
            self.app.update_dac(conv_values)
        else:
            self.app.log(f"Unrecognized data: {line}")


class EyeVoltMCPServer:
    def __init__(self, app: "SerialTUI"):
        self.app = app
        self.host = app.mcp_host
        self.port = app.mcp_port
        self.server = Server("eyevolt")
        self._setup_handlers()

    def log(self, msg: str):
        self.app.mcp_log_queue.put(f"[MCP] {msg}")

    def _setup_handlers(self):
        @self.server.list_tools()
        async def list_tools():
            return [
                Tool(
                    name="get_voltages",
                    description="Get all enabled voltages with their names",
                    inputSchema={"type": "object", "properties": {}}
                ),
                Tool(
                    name="get_voltage",
                    description="Get voltage reading for a channel by its name",
                    inputSchema={
                        "type": "object",
                        "properties": {
                            "name": {
                                "type": "string",
                                "description": "Channel name"
                            }
                        },
                        "required": ["name"]
                    }
                ),
                Tool(
                    name="get_voltage_idx",
                    description="Get voltage reading for a channel by its index (0-11)",
                    inputSchema={
                        "type": "object",
                        "properties": {
                            "channel": {
                                "type": "integer",
                                "description": "Channel index (0-11)"
                            }
                        },
                        "required": ["channel"]
                    }
                ),
                Tool(
                    name="get_channel_info",
                    description="Get information about all channels (name, enabled status, current value)",
                    inputSchema={"type": "object", "properties": {}}
                ),
                Tool(
                    name="get_channel_history",
                    description="Get history data for a channel by its name as percentages (0-100)",
                    inputSchema={
                        "type": "object",
                        "properties": {
                            "name": {
                                "type": "string",
                                "description": "Channel name"
                            }
                        },
                        "required": ["name"]
                    }
                ),
                Tool(
                    name="set_voltage",
                    description="Set the output voltage of a DAC generation channel (0-7). "
                                "Voltage is in volts over the 0-3.3 V range.",
                    inputSchema={
                        "type": "object",
                        "properties": {
                            "channel": {
                                "type": "integer",
                                "description": "DAC channel index (0-7)"
                            },
                            "voltage": {
                                "type": "number",
                                "description": "Target voltage in volts (0-3.3)"
                            }
                        },
                        "required": ["channel", "voltage"]
                    }
                )
            ]

        @self.server.call_tool()
        async def call_tool(name: str, arguments: dict):
            self.log(f"Tool called: {name}({arguments})")
            
            if name == "get_voltages":
                result = {}
                for i in range(12):
                    if self.app.channel_config[i]:
                        result[self.app.static_texts[i]] = self.app.current_values[i]
                return [TextContent(type="text", text=json.dumps(result, indent=2))]
            
            elif name == "get_voltage":
                channel_name = arguments.get("name", "")
                for i in range(12):
                    if self.app.static_texts[i] == channel_name:
                        return [TextContent(type="text", text=str(self.app.current_values[i]))]
                self.log(f"Error: Channel '{channel_name}' not found")
                return [TextContent(type="text", text=f"Error: Channel '{channel_name}' not found")]
            
            elif name == "get_voltage_idx":
                channel = arguments.get("channel", 0)
                if channel < 0 or channel >= 12:
                    self.log(f"Error: Invalid channel {channel}")
                    return [TextContent(type="text", text=f"Error: Channel must be 0-11")]
                return [TextContent(type="text", text=str(self.app.current_values[channel]))]
            
            elif name == "get_channel_info":
                info = []
                for i in range(12):
                    max_val = 3.3 if i < 8 else 6.6
                    info.append({
                        "channel": i,
                        "name": self.app.static_texts[i],
                        "enabled": self.app.channel_config[i],
                        "voltage": self.app.current_values[i],
                        "max_voltage": max_val
                    })
                return [TextContent(type="text", text=json.dumps(info, indent=2))]
            
            elif name == "get_channel_history":
                channel_name = arguments.get("name", "")
                for i in range(12):
                    if self.app.static_texts[i] == channel_name:
                        display = self.app.displays[i] if self.app.displays else None
                        history = display.history if display else []
                        return [TextContent(type="text", text=json.dumps(history))]
                self.log(f"Error: Channel '{channel_name}' not found")
                return [TextContent(type="text", text=f"Error: Channel '{channel_name}' not found")]

            elif name == "set_voltage":
                channel = arguments.get("channel", -1)
                voltage = arguments.get("voltage", 0.0)
                if not isinstance(channel, int) or channel < 0 or channel >= 8:
                    self.log(f"Error: Invalid DAC channel {channel}")
                    return [TextContent(type="text", text=f"Error: DAC channel must be 0-7")]
                try:
                    voltage = float(voltage)
                except (TypeError, ValueError):
                    return [TextContent(type="text", text="Error: voltage must be a number")]
                if voltage < 0 or voltage > 3.3:
                    return [TextContent(type="text", text="Error: voltage must be 0-3.3 V")]
                millivolts = round(voltage * 1000)
                sent = self.app.send_command(f"SETMV {channel} {millivolts}")
                if not sent:
                    return [TextContent(type="text", text="Error: serial connection not available")]
                self.log(f"Set DAC{channel} to {voltage:.3f} V ({millivolts} mV)")
                return [TextContent(type="text",
                                    text=f"Set DAC{channel} to {voltage:.3f} V ({millivolts} mV)")]

            return [TextContent(type="text", text=f"Unknown tool: {name}")]

    def create_app(self):
        sse = SseServerTransport("/messages")

        async def handle_sse(request):
            self.log(f"SSE connection from {request.client.host if request.client else 'unknown'}")
            async with sse.connect_sse(
                request.scope, request.receive, request._send
            ) as streams:
                await self.server.run(
                    streams[0], streams[1], self.server.create_initialization_options()
                )

        async def handle_messages(request):
            await sse.handle_post_message(request.scope, request.receive, request._send)

        return Starlette(
            routes=[
                Route("/sse", endpoint=handle_sse),
                Route("/messages", endpoint=handle_messages, methods=["POST"])
            ]
        )

    def serve(self):
        self.log(f"Server listening on {self.host}:{self.port}")
        starlette_app = self.create_app()
        uvicorn.run(starlette_app, host=self.host, port=self.port, log_level="warning")


class SerialTUI(App):
    CSS = """
    Screen {
        layout: grid;
        grid-size: 3 4;
        align: center middle;
    }
    #dac_section {
        dock: bottom;
        height: 4;
        border-top: solid $primary;
        padding: 0 1;
    }
    #dac_title {
        height: 1;
        text-style: bold;
    }
    #dac_grid {
        layout: grid;
        grid-size: 4 2;
        height: 2;
        align: center middle;
    }
    Sparkline {
        min-height: 4;
    }
    """

    def __init__(self, serial_port: str, static_texts: list[str], channel_config: list[bool], 
                 history_limit: int, mcp_enabled: bool = False, mcp_host: str = "127.0.0.1", 
                 mcp_port: int = 8088, **kwargs):
        super().__init__(**kwargs)
        self.serial_port = serial_port
        self.static_texts = static_texts
        self.channel_config = channel_config
        self.history_limit = history_limit
        self.current_values = [0.0] * 12
        self.displays = []
        self.dac_values = [0.0] * 8
        self.dac_displays = []
        self.serial_protocol: SerialProtocol | None = None
        self._loop: asyncio.AbstractEventLoop | None = None
        self.mcp_enabled = mcp_enabled
        self.mcp_host = mcp_host
        self.mcp_port = mcp_port
        self.mcp_server: EyeVoltMCPServer | None = None
        self.mcp_log_queue: queue.Queue = queue.Queue()
        self.logger = logging.getLogger("eyevolt")

    def compose(self) -> ComposeResult:
        for i in range(12):
            yield VoltageDisplay(
                self.static_texts[i],
                i,
                enabled=self.channel_config[i],
                history_limit=self.history_limit,
                id=f"voltage_{i}"
            )
        with Vertical(id="dac_section"):
            yield Label("DAC readback", id="dac_title")
            with Vertical(id="dac_grid"):
                for i in range(8):
                    yield DacDisplay(f"DAC{i}", i, id=f"dac_{i}")

    async def on_mount(self) -> None:
        self.log(f"Mounting TUI with serial port: {self.serial_port}")
        self.displays = [self.query_one(f"#voltage_{i}", VoltageDisplay) for i in range(12)]
        self.dac_displays = [self.query_one(f"#dac_{i}", DacDisplay) for i in range(8)]
        asyncio.create_task(self.read_serial())
        
        if self.mcp_enabled:
            self.set_interval(0.2, self.poll_mcp_logs)
            self.log(f"Starting MCP server on {self.mcp_host}:{self.mcp_port}")
            self.mcp_server = EyeVoltMCPServer(self)
            thread = threading.Thread(target=self.mcp_server.serve, daemon=True)
            thread.start()

    def poll_mcp_logs(self):
        try:
            while True:
                msg = self.mcp_log_queue.get_nowait()
                self.log(msg)
        except queue.Empty:
            pass

    async def read_serial(self):
        loop = asyncio.get_running_loop()
        self._loop = loop
        self.log("Opening serial connection...")
        try:
            transport, protocol = await serial_asyncio.create_serial_connection(
                loop,
                lambda: SerialProtocol(self),
                self.serial_port,
                baudrate=9600,
            )
            self.serial_protocol = protocol
            self.log("Serial connection running.")
        except Exception as e:
            self.log(f"Failed to open serial port: {e}")

    def send_command(self, command: str) -> bool:
        """Thread-safe send of an ASCII command to the Pico over serial.

        Returns True if the command was scheduled, False if no serial
        connection is available.
        """
        if (self._loop is None or self.serial_protocol is None
                or self.serial_protocol.transport is None):
            return False
        data = (command + "\n").encode("ascii")
        self._loop.call_soon_threadsafe(self.serial_protocol.transport.write, data)
        return True

    def update_values(self, indices, new_values):
        for idx, val in zip(indices, new_values):
            self.current_values[idx] = val
            self.displays[idx].update_value(val)
        self.refresh()

    def update_dac(self, new_values):
        for i, val in enumerate(new_values):
            self.dac_values[i] = val
            self.dac_displays[i].update_value(val)
        self.refresh()


def parse_text_options(text_option: str) -> dict:
    mapping = {}
    if text_option:
        for pair in text_option.split(","):
            if "=" in pair:
                key, value = pair.split("=", 1)
                mapping[key.strip()] = value.strip()
    return mapping


def parse_channel_options(channel_option: str) -> dict:
    mapping = {}
    if channel_option:
        for pair in channel_option.split(","):
            if "=" in pair:
                key, value = pair.split("=", 1)
                mapping[key.strip()] = value.strip().lower()
    return mapping
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

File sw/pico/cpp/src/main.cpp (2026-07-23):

#include <cstdint>
#include <cstdio>
#include <cstring>

#include "pico/stdlib.h"

#include "pins.h"
#include "monitor.h"
#include "generator.h"
#include "waveform.h"

#ifndef EYEVOLT_VERSION
#define EYEVOLT_VERSION "2.0-cpp-?"
#endif

// ── Serial frame output ──────────────────────────────────────────────────────

static void print_frame(const char *tag, const uint16_t *vals, size_t n) {
    printf("%s::", tag);
    for (size_t i = 0; i < n; i++) {
        printf("%s%05u", i ? " " : "", (unsigned)vals[i]);
    }
    putchar('\n');
}

// ── Command protocol (host → Pico, newline-terminated ASCII) ─────────────────

static char cmd_buf[80];
static size_t cmd_len = 0;

static void print_help() {
    printf("HELP commands (newline-terminated):\n");
    printf("  SETDAC <ch> <raw>   set DAC ch 0-7 duty 0-65535 (-> 0-3.3 V)\n");
    printf("  SETMV  <ch> <mv>    set DAC ch 0-7 to millivolts 0-3300\n");
    printf("  OFF    <ch>         set DAC ch 0-7 to 0 V\n");
    printf("  OFFALL              stop playback + set all DAC channels to 0 V\n");
    printf("  WFLOAD <nsteps> <mask_hex>  upload binary waveform (expect WFREADY, then raw bytes)\n");
    printf("  WFPLAY [loop=0] [step_us=1000]  play loaded waveform\n");
    printf("  WFSTOP              stop playback\n");
    printf("  WFSTATUS            query playback state\n");
    printf("  VERSION             print firmware version\n");
    printf("  HELP                this message\n");
}

// Blocking binary receive for WFLOAD. Pauses monitoring for the ~0.5 s upload;
// USB backpressure (tinyUSB NAKs) provides flow control.
static void receive_waveform(WaveformPlayer &wf) {
    const size_t expected = wf.expected_bytes();
    printf("WFREADY %u\n", (unsigned)expected);

    absolute_time_t deadline = make_timeout_time_ms(pins::WF_UPLOAD_TIMEOUT_MS);
    bool complete = false;
    while (!complete && !time_reached(deadline)) {
        int c = getchar_timeout_us(500);
        if (c >= 0) {
            complete = wf.feed_byte((uint8_t)c);
        }
    }

    if (complete) {
        wf.finish_load();
        printf("OK WFLOADED 0x%08lX\n", (unsigned long)wf.checksum());
    } else {
        printf("ERROR timeout (%u/%u bytes)\n",
               (unsigned)wf.received(), (unsigned)expected);
    }
}

static void handle_command(const char *cmd, Generator &gen, WaveformPlayer &wf) {
    unsigned ch = 0, val = 0, mask = 0, loop = 0, step_us = 0;

    if (sscanf(cmd, " SETDAC %u %u", &ch, &val) == 2) {
        if (ch >= pins::NUM_DAC_CHANNELS || val > pins::DAC_MAX_RAW) {
            printf("ERROR bad args (ch 0-%u, raw 0-%u)\n",
                   pins::NUM_DAC_CHANNELS - 1, pins::DAC_MAX_RAW);
            return;
        }
        gen.set_raw(ch, (uint16_t)val);
        printf("OK DAC%u=%u\n", ch, val);
    } else if (sscanf(cmd, " SETMV %u %u", &ch, &val) == 2) {
        if (ch >= pins::NUM_DAC_CHANNELS || val > pins::DAC_FULLSCALE_MV) {
            printf("ERROR bad args (ch 0-%u, mv 0-%u)\n",
                   pins::NUM_DAC_CHANNELS - 1, pins::DAC_FULLSCALE_MV);
            return;
        }
        gen.set_millivolts(ch, (uint16_t)val);
        printf("OK DAC%u=%umV\n", ch, val);
    } else if (sscanf(cmd, " OFF %u", &ch) == 1) {
        if (ch >= pins::NUM_DAC_CHANNELS) {
            printf("ERROR bad channel (0-%u)\n", pins::NUM_DAC_CHANNELS - 1);
            return;
        }
        gen.off(ch);
        printf("OK DAC%u=0\n", ch);
    } else if (strncmp(cmd, "OFFALL", 6) == 0) {
        // Emergency "all to zero": stop any running waveform first, otherwise
        // the timer would re-drive the active channels on its next tick.
        wf.stop();
        gen.off_all();
        printf("OK all DAC=0\n");
    } else if (sscanf(cmd, " WFLOAD %u %x", &val, &mask) == 2) {
        // val = nsteps, mask = active-channel bitmask.
        if (wf.is_playing()) wf.stop();
        if (!wf.begin_load((uint16_t)val, (uint8_t)mask)) {
            printf("ERROR bad nsteps (1-%u)\n", pins::WF_MAX_STEPS);
            return;
        }
        receive_waveform(wf);   // prints WFREADY, then the ack or timeout
    } else if (strncmp(cmd, "WFPLAY", 6) == 0) {
        // Optional args: loop (0/1) and step_us. Missing args keep defaults.
        int n = sscanf(cmd, " WFPLAY %u %u", &loop, &step_us);
        if (n < 2) step_us = pins::WF_DEFAULT_STEP_US;
        if (n < 1) loop = 0;
        if (wf.state() == WfState::IDLE) {
            printf("ERROR no waveform loaded\n");
            return;
        }
        if (wf.is_playing()) {
            printf("ERROR already playing\n");
            return;
        }
        if (!wf.play(gen, loop != 0, step_us)) {
            printf("ERROR could not start playback\n");
            return;
        }
        printf("OK PLAYING nsteps=%u mask=0x%02X loop=%u step_us=%lu\n",
               wf.nsteps(), wf.mask(), (unsigned)(loop != 0),
               (unsigned long)wf.step_us());
    } else if (strncmp(cmd, "WFSTOP", 6) == 0) {
        uint16_t at = wf.step();
        wf.stop();
        printf("OK STOPPED step=%u\n", at);
    } else if (strncmp(cmd, "WFSTATUS", 8) == 0) {
        printf("WFSTAT %s %u %u 0x%02X\n",
               WaveformPlayer::state_name(wf.state()),
               wf.step(), wf.nsteps(), wf.mask());
    } else if (strncmp(cmd, "VERSION", 7) == 0) {
        printf("VERSION %s\n", EYEVOLT_VERSION);
    } else if (strncmp(cmd, "HELP", 4) == 0) {
        print_help();
    } else {
        printf("ERROR unknown command: '%s' (try HELP)\n", cmd);
    }
}

static void poll_commands(Generator &gen, WaveformPlayer &wf) {
    int c;
    while ((c = getchar_timeout_us(0)) != PICO_ERROR_TIMEOUT && c >= 0) {
        if (c == '\r' || c == '\n') {
            if (cmd_len > 0) {
                cmd_buf[cmd_len] = '\0';
                handle_command(cmd_buf, gen, wf);
                cmd_len = 0;
            }
        } else if (cmd_len < sizeof(cmd_buf) - 1) {
            cmd_buf[cmd_len++] = (char)c;
        }
    }
}

// ── Main loop ────────────────────────────────────────────────────────────────
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

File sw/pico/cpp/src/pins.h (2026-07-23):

#pragma once

//
// EyeVolt 2.0 — Pico (RP2040) hardware pin map.
//
// Source of truth for the v2.0 PCB. See the project README.md section
// "Pico pin mapping (2.0 hardware)". Key differences from v1.1:
//   * MUX0 and MUX1 are CASCADED; all 12 monitor channels exit on GP26 only.
//   * S0 and S2 are swapped on both monitor muxes vs v1.1.
//   * GP27 is now the DAC-feedback ADC (was MUX1 monitor ADC in v1.1).
//   * GP2-GP9 drive the 8 PWM generation outputs (new in v2.0).
//

namespace pins {

// ── Monitor mux MUX0 (U11): 8 low-voltage channels ──────────────────────────
// (S0/S2 swapped vs v1.1: v1.1 had S0=GP10, S2=GP12)
constexpr unsigned MUX0_S0 = 12;
constexpr unsigned MUX0_S1 = 11;
constexpr unsigned MUX0_S2 = 10;
constexpr unsigned MUX0_EN = 13;   // ~E, active low

// ── Monitor mux MUX1 (U10): HV channels CH0-3, cascade MUX0 on CH4 ───────────
// (S0/S2 swapped vs v1.1: v1.1 had S0=GP21, S2=GP19)
constexpr unsigned MUX1_S0 = 19;
constexpr unsigned MUX1_S1 = 20;
constexpr unsigned MUX1_S2 = 21;
constexpr unsigned MUX1_EN = 18;   // ~E, active low

// MUX1 channel that taps the cascaded MUX0 bank (low-voltage inputs).
constexpr unsigned MUX1_CASCADE_CHANNEL = 4;

// ── DAC feedback mux U12: reads back 8 generated outputs ─────────────────────
constexpr unsigned DACMUX_S0 = 15;
constexpr unsigned DACMUX_S1 = 14;
constexpr unsigned DACMUX_S2 = 16;
constexpr unsigned DACMUX_EN = 17;   // ~E, active low

// ── ADC inputs ───────────────────────────────────────────────────────────────
// RP2040 ADC input number (not the GPIO number): input 0 = GP26, input 1 = GP27.
constexpr unsigned ADC_MONITOR  = 0;   // GP26 — all 12 monitor channels (via MUX1)
constexpr unsigned ADC_READBACK = 1;   // GP27 — 8 generated-output readback (via U12)

constexpr unsigned ADC_MONITOR_PIN  = 26;
constexpr unsigned ADC_READBACK_PIN = 27;

// ── PWM generation outputs (GP2-GP9 → DAC_PWM0..7) ───────────────────────────
constexpr unsigned DAC_PWM_FIRST = 2;    // DAC_PWM0 = GP2
constexpr unsigned NUM_DAC_CHANNELS = 8;

// ── Channel counts ───────────────────────────────────────────────────────────
constexpr unsigned NUM_LV_CHANNELS      = 8;   // channels 0-7  (0 - 3.3 V)
constexpr unsigned NUM_HV_CHANNELS      = 4;   // channels 8-11 (0 - 6.6 V)
constexpr unsigned NUM_MONITOR_CHANNELS = 12;

// ── Timing ───────────────────────────────────────────────────────────────────
// Settle time after switching a mux before sampling the ADC.
// The buffers (MCP6L04 / OPA316) and the 74HCT4051 settle in well under 1 us;
// 1 ms is a very safe margin and yields a fast (~50 Hz) refresh.
constexpr unsigned MUX_SETTLE_US      = 1000;
constexpr unsigned READBACK_SETTLE_US = 1000;

// ADC samples averaged per reading to suppress RP2040 ADC noise.
constexpr unsigned ADC_OVERSAMPLE = 4;

// Full-scale of the generation outputs (3.3 V rail), in millivolts.
constexpr unsigned DAC_FULLSCALE_MV = 3300;
constexpr unsigned DAC_MAX_RAW      = 65535;

// ── Waveform playback ────────────────────────────────────────────────────────
// Max steps in a loaded waveform. Buffer size = WF_MAX_STEPS * 8 ch * 2 B.
constexpr unsigned WF_MAX_STEPS         = 2048;   // 32 KB @ 8 channels
constexpr unsigned WF_DEFAULT_STEP_US   = 1000;   // 1 ms/step → 2.048 s full run
constexpr unsigned WF_MIN_STEP_US       = 200;    // 5000 steps/s upper bound
constexpr unsigned WF_MAX_STEP_US       = 100000; // 10 steps/s lower bound
constexpr unsigned WF_UPLOAD_TIMEOUT_MS = 5000;   // abort a stalled binary upload

}  // namespace pins

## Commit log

2024-02-08 Add documentation for RPi Pico, + analog mux
2024-05-20 Add RPi Pico Kicad library
2024-06-01 Add more pdfs
    [MCP6024-I_SL.step, eyevolt.kicad_sch]
2024-06-01 Add a PSB imported from another project
    [eyevolt.kicad_pcb]
2024-06-09 First version of PCB completed
    [eyevolt.kicad_pcb, eyevolt.kicad_sch]
2024-06-09 Add Gerber files sent to JLCPCB
    [eyevolt-B_Cu.gbl, eyevolt-B_Mask.gbs, eyevolt-B_Paste.gbp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]
2025-04-08 Add first version of software for both pico and PC
2025-04-08 Add progress bar to voltage display
2025-04-09 Fix schematic errors - Regenerate a PCB for version 1.1
    [eyevolt-B_Cu.gbl, eyevolt-B_Mask.gbs, eyevolt-B_Paste.gbp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]
2026-03-05 Add hardware documentation and MicroPython conversion guide
    - Add connectors diagram (drawio)
    - Add schematic PDF
    - Add MicroPython conversion documentation
2026-03-05 Add MCP server and update PC application
    - Add MCP server with voltage monitoring tools
    - Refactor tools: get_voltages returns enabled channels with names
    - Add get_voltage (by name) and get_voltage_idx (by index)
    - Update get_channel_history to use channel names
2026-03-05 Add MicroPython firmware for Pico
    - Add boot.py and main.py for voltage reading
    - Add Makefile for deployment
2026-06-10 Add KiCAD-MCP-Server mcp server setup
2026-06-11 Start new 2.0 version with 8 PWM-based DAC
    [eyevolt.kicad_pcb, eyevolt.kicad_sch]
2026-06-15 cleaning sche
    [eyevolt.kicad_pcb, eyevolt.kicad_sch]
2026-06-15 cleaned schematic, component placement on layout
    [eyevolt.kicad_pcb, eyevolt.kicad_sch]
2026-06-18 layout finished
    [eyevolt.kicad_pcb]
2026-06-22 as sent for FAB
    [eyevolt-B_Cu.gbl, eyevolt-B_Mask.gbs, eyevolt-B_Paste.gbp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]
2026-07-15 Add waveform playback firmware + PWL host tools
    Firmware (sw/pico/cpp):
    - WaveformPlayer: upload 8ch x up to 2048-step waveforms into SRAM and
    play them back via a repeating hardware timer (WFLOAD/WFPLAY/WFSTOP/
    WFSTATUS). Inactive channels hold their manual value during playback.
    - OFFALL now also stops any running waveform before zeroing the DACs.
    - Custom USB-CDC identification (EyeVolt / EyeVolt 2.0).
    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
2026-07-15 Add top-level Pico Makefile (build/upload/reset)
    Thin wrapper over sw/pico/cpp that delegates build/flash to the
    firmware directory and adds a reset-only target using the pico-bootstrap
    openocd install. `make all` builds, uploads, and resets the board.
